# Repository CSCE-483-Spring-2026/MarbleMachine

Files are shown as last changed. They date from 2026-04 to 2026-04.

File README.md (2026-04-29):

Pi Username: marble

Pi Password: raspberry

This is a link to a demo video: https://drive.google.com/file/d/19KJHCajNt0oRb57q_G2E8B0M9cy8NJ1L/view?usp=sharing 

This is a link to a hardware overview: https://drive.google.com/file/d/1OxgzBftDdnBZCayo8GF6vSUFwVKjy-8R/view?usp=sharing 

The SD card should have a Linux OS already installed. You can shh into the pi with "ssh marble@whatever.the.ip.adress.is". You may have to plug the pi into a monitor to initially find the IP address. We found that setting up Raspberry Pi Connect made everything much easier, but you can choose how to connect after the basic setup. Watch the hardware overview to see how to access the pi.

If you are using the SD card currently in the pi everything should be mostly setup. You should be able to open the terminal, cd into MarbleMachine, type "sudo ./setupNoVenv.sh". Open up a web browser, and it should automatically open to local host. If you see any pop-ups or tabs about key rings, make sure to close them so localhost will open. Now you can enter inputs into the website, the machine won't start running until you hit submit. Now you can skip to the "Frequencies must be one of 5 options:" paragraph.

If you are starting from scratch with a new or wiped SD card, following the instructions here:

You will need to set up your Raspberry Pi. If you don’t know how to set up a pi, look at their website for basic instructions. 

You will need to set up an Apache web server. We followed a tutorial from Tom’s Hardware: https://www.tomshardware.com/news/raspberry-pi-web-server,40174.html. There are other instructions on the internet if you want to find a different way to set up.

Connect your git repository to your Pi. We already had this knowledge, but again, you can find lots of tutorials on the internet if you need more information on how to complete this task.

Run setup.sh. This script does three things. First, it clears any old garbage in /var/www/html. Second, it installs the necessary Python libraries to operate the color sensor. Third, it copied all web server files to /var/www/html. If this fails, you will need to look into what errors you’re getting. Usually, they were fairly descriptive and you might have to download installs. Feel free to contact us, but also Google is a thing.

Go to localhost on the Pi.

Setup the marbles to run. Look at main.py for more information.

Frequencies must be one of 5 options: ThirtySeconds, TwoMinutes, TwelveHours, Daily, or Weekly. These run at the time intervals you would expect based on their names.
It is important to spell these correctly.
Start Day can be any of the days of the week. Spell it using the full name of the day with a capital letter, i.e. Wednesday.
Start time is done in military time, so anything from 0:00 to 23:59. 

Click submit when all are filled in. 

Check the debug on the php page. If the json file was not successfully created, the first thing you should check is the file permissions for connect.php and marbles.json. The user www-data needs to have execute and write permission. Google was really helpful with this if you’re not confident about changing permissions. 

If the JSON file was successfully created, the marble machine should now be running successfully. If the hardware is connected and the marbles are in the run, they should be dropped at the proper time. The color sensor is also run off main.py, so everything is good from here. See the Hardware Demo section for a demonstration of proper functionality and information on debugging the hardware.

There will be a log script in logs/* in case you are still trying to debug the code after executing. The log file only reads from the python’s stderr output stream. Note this if you are trying to debug any code executed within main.py.
Have fun! Do things! You’ve got this, there are many ways to expand on this project, do something cool and tell us what you did if you’re proud of it!

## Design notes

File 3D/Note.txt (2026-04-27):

These are the final 3D Models. Some of the final printed parts are of old versions. I got new filament that was bad and couldn't really print anything.

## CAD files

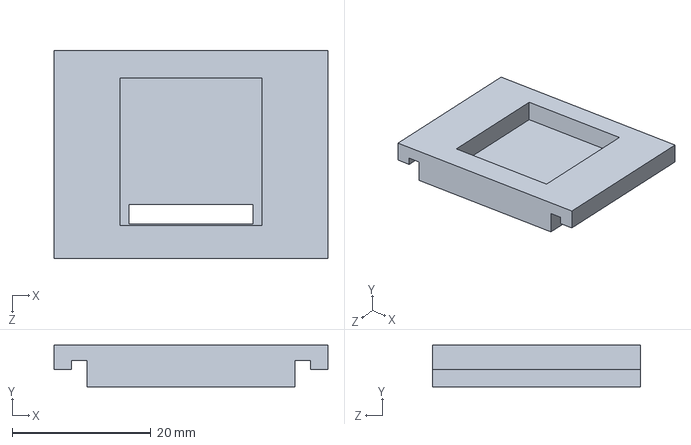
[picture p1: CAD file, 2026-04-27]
3D/SolidWorks/Color Sensor Housing v - Bottom.SLDPRT
39.5 x 6.00 x 30.0 mm

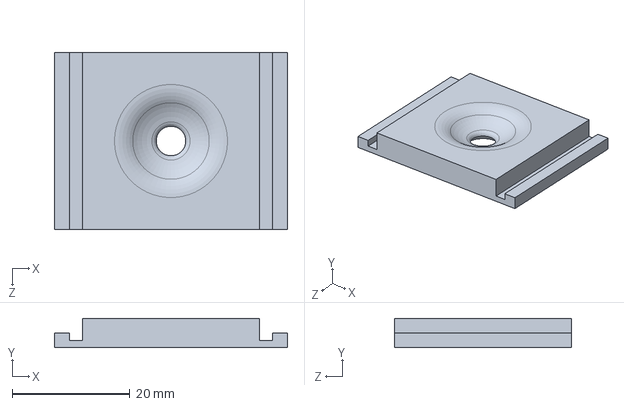
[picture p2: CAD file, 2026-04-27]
3D/SolidWorks/Color Sensor Housing v - Top.SLDPRT
39.5 x 5.00 x 30.0 mm

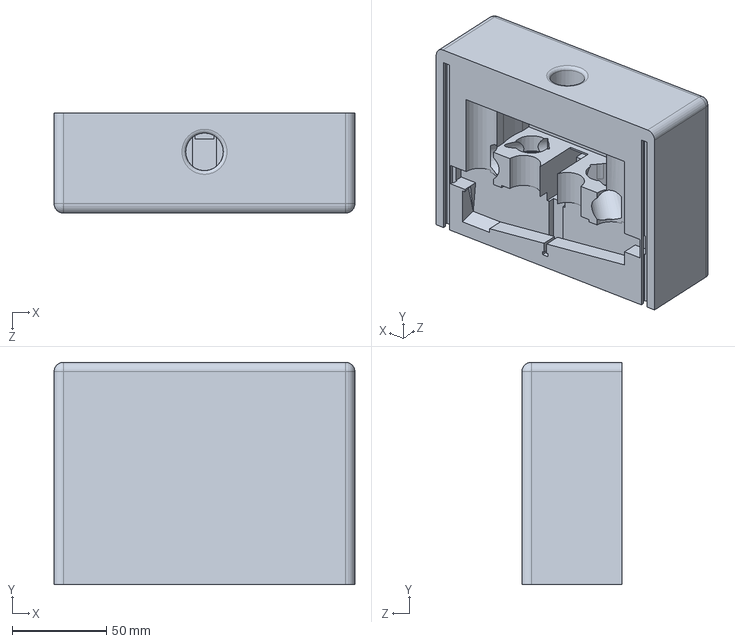
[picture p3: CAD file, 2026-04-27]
3D/SolidWorks/Body v5.0 - F Half.SLDPRT
160.0 x 118.2 x 53.3 mm

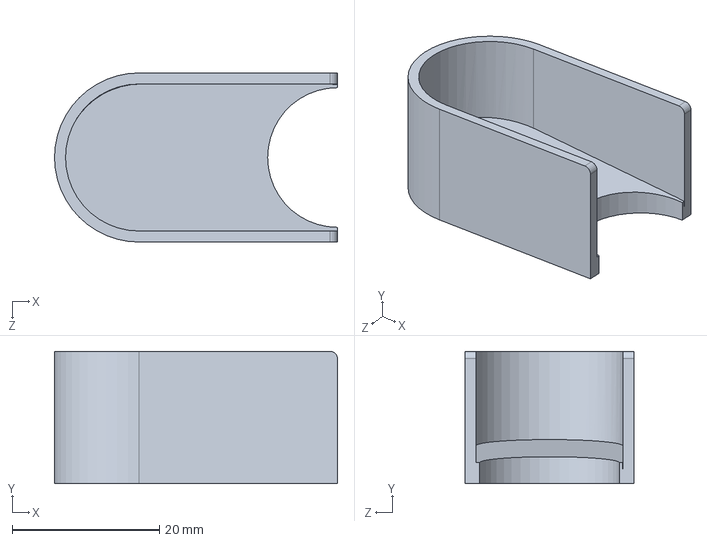
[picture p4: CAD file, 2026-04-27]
3D/SolidWorks/Swivel Arm v2.SLDPRT
38.5 x 18.0 x 23.0 mm

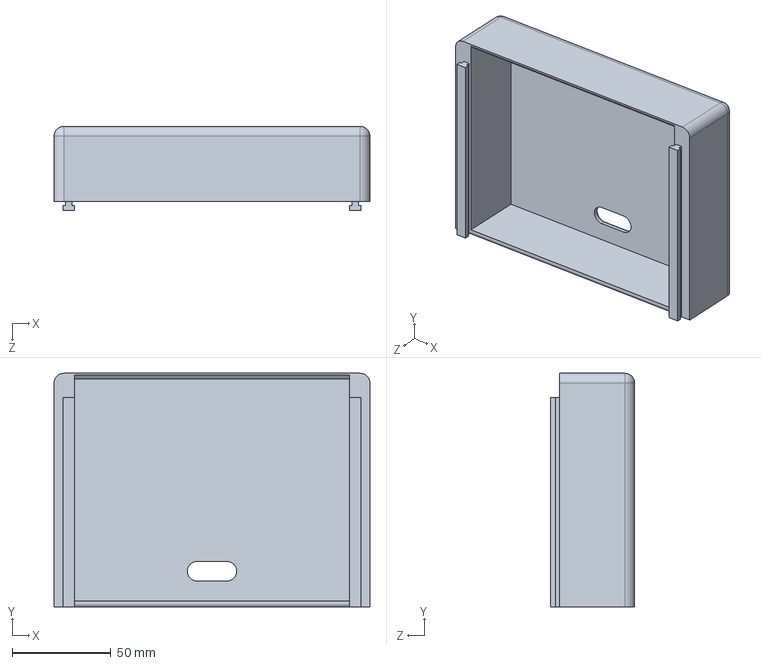
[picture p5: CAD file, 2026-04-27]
3D/SolidWorks/PiHousing.SLDPRT
160.0 x 118.2 x 42.8 mm

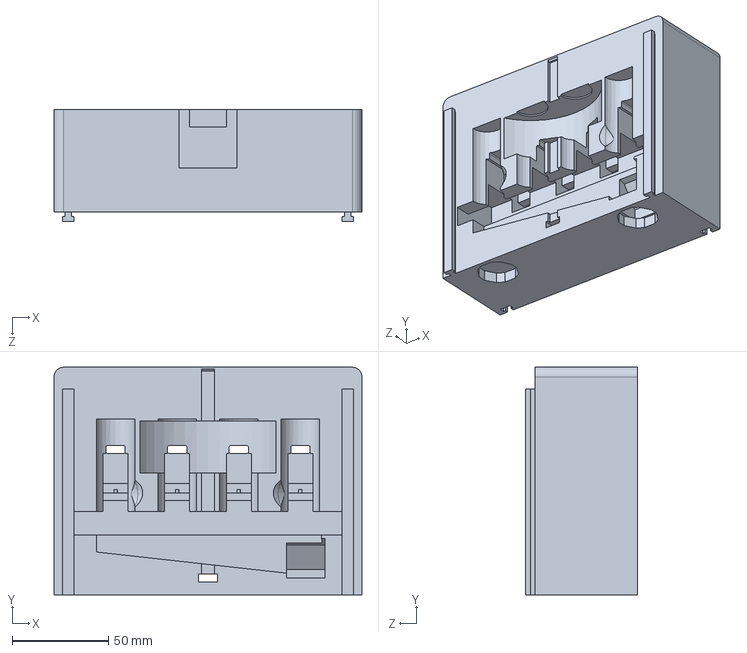
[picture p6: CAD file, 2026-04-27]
3D/SolidWorks/Body v5.0 - M Half.SLDPRT
160.0 x 118.2 x 58.0 mm

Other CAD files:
3D/Body v5.0 - F Half.3MF
3D/Body v5.0 - M Half.3mf
3D/Color Sensor Housing v - Bottom.3MF
3D/Color Sensor Housing v - Top.3MF
3D/PiHousing.3MF
3D/Swivel Arm v2.3MF

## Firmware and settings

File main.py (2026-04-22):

import RPi.GPIO as GPIO
import time
import json
import datetime
import threading
import yaml
import board
import adafruit_tcs34725

i2c = board.I2C()
sensor = adafruit_tcs34725.TCS34725(i2c)

GPIO.setmode(GPIO.BCM)

#Pin Assignments (see wiring diagram):
SERVO_RED = 17
SERVO_YELLOW = 27
SERVO_GREEN = 22
SERVO_BLUE = 5
SERVO_SORT = 6


SERVOS = [SERVO_RED, SERVO_YELLOW, SERVO_GREEN, SERVO_BLUE, SERVO_SORT] #later add additional 'sorting' servos

# INITIALIZATION:

#servo init
# for pin in SERVOS:
#     GPIO.setup(pin, GPIO.OUT)

#software pmw
pwm = {}

for pin in SERVOS:
    GPIO.setup(pin, GPIO.OUT)
    #this makes a 'pwm instance'
    p_i = GPIO.PWM(pin, 50) # 50 hz frequency
    p_i.start(0)
    pwm[pin] = p_i


def setAngle(angle, pin):
    #angle to duty cycle
    duty = (angle / 18) + 2.5 #this equation converts angle to duty cycle for 50hz
    pwm[pin].ChangeDutyCycle(duty)
    time.sleep(0.5)
    pwm[pin].ChangeDutyCycle(0)

def move_open(pin):
    setAngle(125, pin)

def move_closed(pin):
    #90 might be closed position for 3d print setup
    setAngle(90, pin)

def moving_servos(pin, frequency, start_day, start_time):

    next_trigger = calculate_next_trigger(start_day, start_time)

    while True:
        now = datetime.datetime.now()
        delay = (next_trigger - now).total_seconds()

        if delay > 0:
            time.sleep(delay)
        
        #open
        move_open(pin)
        time.sleep(0.1)
        move_closed(pin)

        #reset delays:

        if frequency == "ThirtySeconds":
            next_trigger += datetime.timedelta(seconds=30)

        if frequency == "TwoMinutes":
            next_trigger += datetime.timedelta(minutes=2)

        if frequency == "TwelveHours":
            next_trigger += datetime.timedelta(hours=12)

        if frequency == "Daily":
            next_trigger += datetime.timedelta(days=1)
        
        if frequency == "Weekly":
            next_trigger += datetime.timedelta(days=7)


DaysOfWeek = {
    "Monday" : 0,
    "Tuesday" : 1,
    "Wednesday" : 2,
    "Thursday" : 3,
    "Friday" : 4,
    "Saturday" : 5,
    "Sunday" : 6
}

def calculate_next_trigger(start_day, start_time):

    now = datetime.datetime.now() #gets current time
    weekday_number = DaysOfWeek[start_day] 

    #given time = 12:26, hour = 12, min=26
    hour,minute = map(int, start_time.split(":"))
 
    remaing_days = weekday_number - now.weekday()
    if remaing_days < 0:
        remaing_days += 7

    next_trigger = now.replace(hour=hour, minute=minute, second=0, microsecond=0)
    next_trigger += datetime.timedelta(days=remaing_days)
    if next_trigger <=now:
        next_trigger += datetime.timedelta(days=7)

    return next_trigger

def color_sensor():
    while True:
        #there are also temperature and lux readings if we end up needing them
        color_rgb = sensor.color_rgb_bytes
        print(f"RGB: {color_rgb}")

        #MY LINE TESTING
        if color_rgb[0] >= 70 and color_rgb[1] <= 5 and color_rgb[2] <=5 :
            print("RED!")
            setAngle(180, SERVO_SORT) #NEED TO DETERMINE NUMBERS FOR EACH COLOR
            time.sleep(2)

        elif color_rgb[0] >= 40 and color_rgb[1] == 0 and color_rgb[2] == 0:
            print("RED!")
            setAngle(180, SERVO_SORT)
            time.sleep(2)
        
        elif color_rgb[0] >= 100 and color_rgb[1] <= 10 and color_rgb[2] <= 10:
            print("RED!")
            setAngle(180, SERVO_SORT)
            time.sleep(2)

        elif color_rgb[0] == 45 and color_rgb[1] == 45 and color_rgb[2] <= 20:
            print("GREEN!")
            setAngle(42, SERVO_SORT)
            time.sleep(2)

        elif color_rgb[0] == color_rgb[1] and color_rgb[2] <= 10:
            print("GREEN!")
            setAngle(42, SERVO_SORT)
            time.sleep(2)
        
        elif color_rgb[0] > 10 and color_rgb[0] <20 and color_rgb[2] < color_rgb[0]:
            print("GREEN!")
            setAngle(42, SERVO_SORT)
            time.sleep(2)
        
        elif color_rgb[0] != 0 and color_rgb[0] == color_rgb[1] and color_rgb[0] >=25:
            print("BLUE!")
            setAngle(0, SERVO_SORT)
            time.sleep(2)
        
        elif color_rgb[0] != 0 and color_rgb[0] == color_rgb[2]:
            print("BLUE!")
            setAngle(0, SERVO_SORT)
            time.sleep(2)
        
        elif color_rgb[0] != 0 and color_rgb[1] != 0:
            print("YELLOW!")
            setAngle(138, SERVO_SORT)
            time.sleep(2)
        else:
            print("idk...???")


        time.sleep(1.0)



def readYaml(filename):
    with open(filename, 'r') as file:
        return yaml.safe_load(file)
    #should return with format {marbleColor: {'Start': startTime, 'Period': PeriodSet}}


yaml_data = readYaml('marbles.json')

#format like this maybe?
#!!! note capitaliation
#{"redFreq":"Daily", "redStartDay":"Monday", "redStartTime":"12:26","yellowFreq":"Weekly" ...,"greenFreq":"Weekly" ...,"blueFreq":"Daily" ...}

# should be daily or weekly
red_delay = (yaml_data['redFreq'])
yellow_delay = (yaml_data['yellowFreq'])
green_delay = (yaml_data['greenFreq'])
blue_delay = (yaml_data['blueFreq'])


# should be input as days of the week
red_start_day = (yaml_data['redStartDay'])
yellow_start_day = (yaml_data['yellowStartDay'])
green_start_day = (yaml_data['greenStartDay'])
blue_start_day = (yaml_data['blueStartDay'])

red_start_time = (yaml_data['redStartTime'])
yellow_start_time = (yaml_data['yellowStartTime'])
green_start_time = (yaml_data['greenStartTime'])
blue_start_time = (yaml_data['blueStartTime'])

servo_delays = [red_delay, yellow_delay, green_delay, blue_delay]
start_days = [red_start_day, yellow_start_day, green_start_day, blue_start_day]
start_times = [red_start_time, yellow_start_time, green_start_time, blue_start_time]

threads = []

for i in range(4):
    thread_i = threading.Thread(target=moving_servos, args=(SERVOS[i], servo_delays[i], start_days[i], start_times[i])) #add start time to args
    thread_i.daemon = True #this is important apparently, kills threads because they'll never end
    threads.append(thread_i)

threads_color = threading.Thread(target=color_sensor)
threads_color.daemon = True
threads_color.start()

for i in range(4):
    threads[i].start()



#testing
try:
    while True:
        time.sleep(1) 
 

except KeyboardInterrupt:
    print('key board interupt')
    for i in pwm.values(): 
        i.stop()
    GPIO.cleanup()

#i dont think this is working ?
# for i in pwm.values(): 
#     i.stop()
# GPIO.cleanup()

#data = readFile('marbles')
#print(data)

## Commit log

2026-02-17 testing for one servo
2026-02-18 Update main.py
    using software pwm instead
2026-02-18 add color sensor test file
2026-02-18 Update color_sensor.py
    code from adafruit for testing sensor
2026-02-23 Fix iteration over pwm to use values method
    [main.py]
2026-04-01 integrating sort servo and color sensor
    a marbl-ous commit :)
    (unless it doesnt work then thats my b)
2026-04-08 website starts servos now
2026-04-29 Update README.md
    moved raspberry pi setup instruction
